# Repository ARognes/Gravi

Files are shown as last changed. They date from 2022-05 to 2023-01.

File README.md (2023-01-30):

# Gravi

This is a 42 or 36 key, bluetooth keyboard with at least 100mAh battery life per side

Idk exactly what to call this keyboard. The main focus of it is to eliminate the extra area where the system on a chip (SoC) is commonly located. However I've gotten carried away and removed much more. 

A minimal amount of tenting will be required to hold the battery underneath.

## Names:
- Estoc
- Crawlerboard
- Gravby
- Gravbi
- Gravi
- Gravi
- Mash
- Contour Split
- Ergo Berry
- Skeleberry
- DexBerry

## Features:
- Split in 2 halves
- Bluetooth low energy
- nRF52 family
- On-board SMD components
- No center microcontroller area
- Minimal visible space without keys
- Battery underneath tenting towards usb-c edge
- Milmax sockets

There may be 2 sizes for standard and low profile switch types
- Cherry MX / Kailh
- Kailh choc

The main focus is the Kailh choc board (low profile).

Rohs and FCC compliance will be a hurdle.
A case will need to be built, by this time aesthetics will be more of a concern.

# Schematic
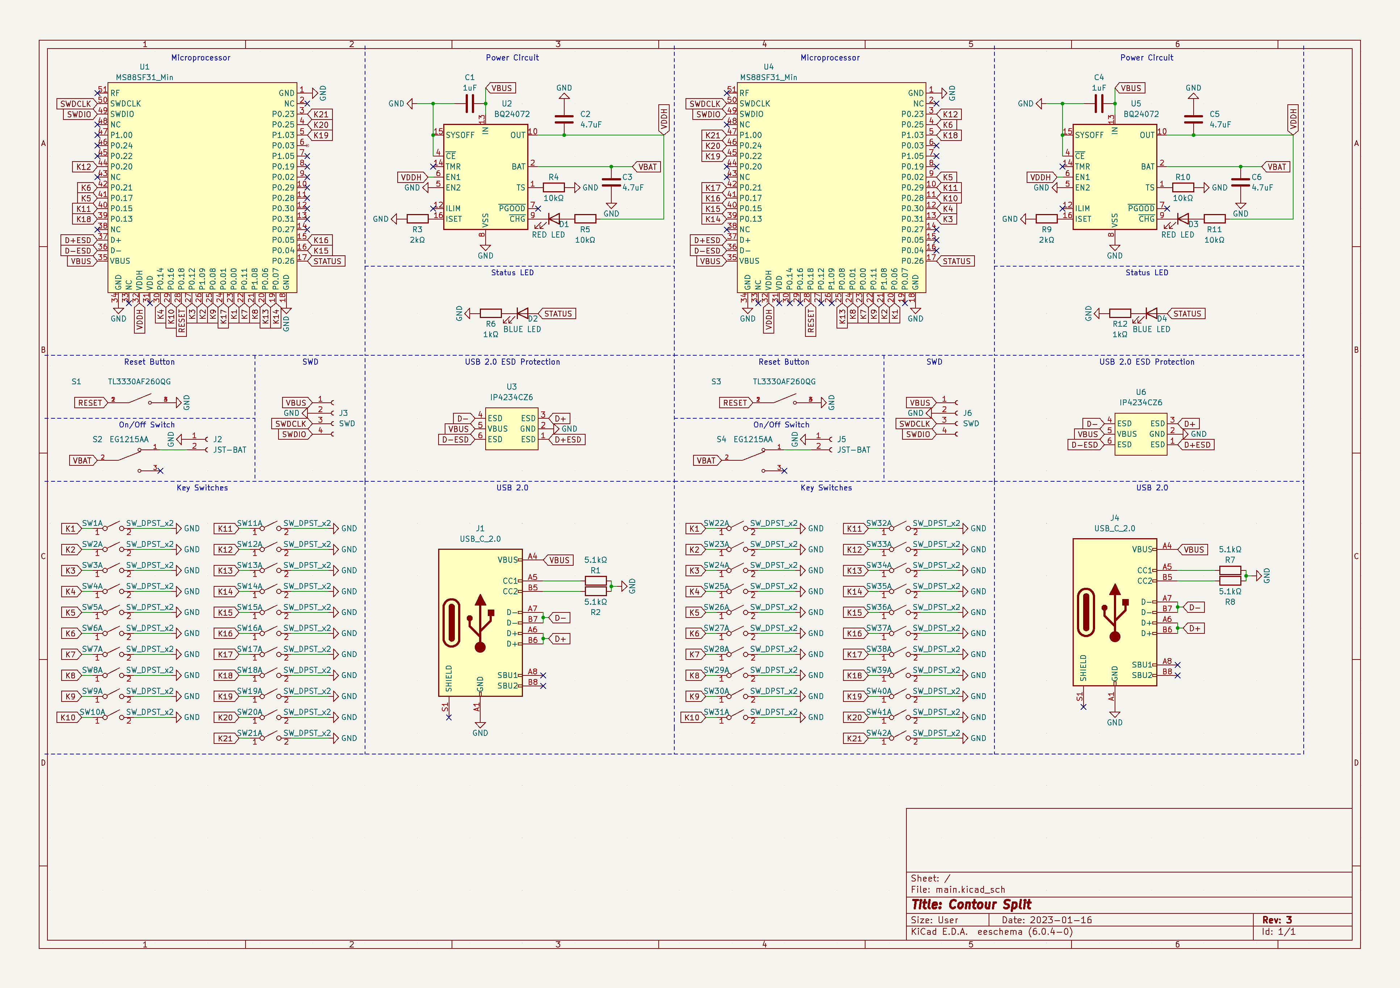
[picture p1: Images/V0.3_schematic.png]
Schematic

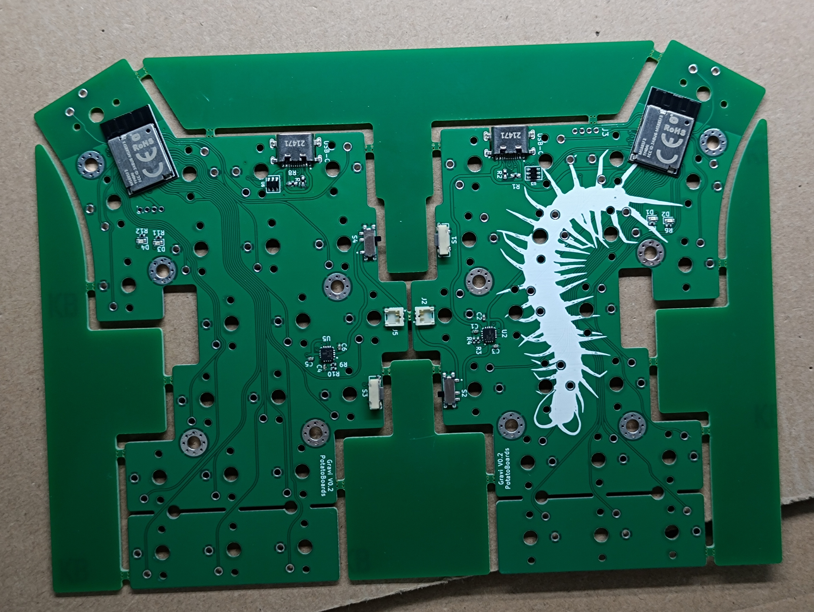
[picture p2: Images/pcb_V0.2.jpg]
Render


# Prototypes
Prototype

# Revision 4
(Looks the same as rev 3)

# Revision 3
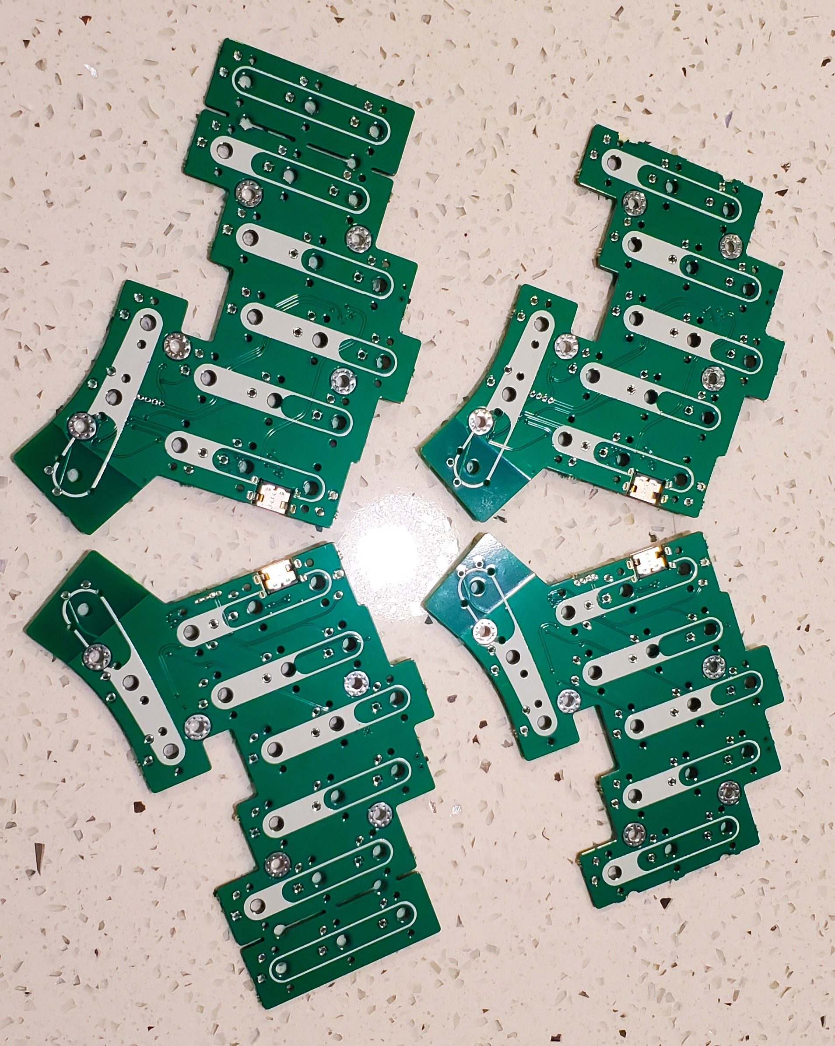
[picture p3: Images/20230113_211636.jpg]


# Revision 2
(Looks the same as rev 3)

# Revision 1
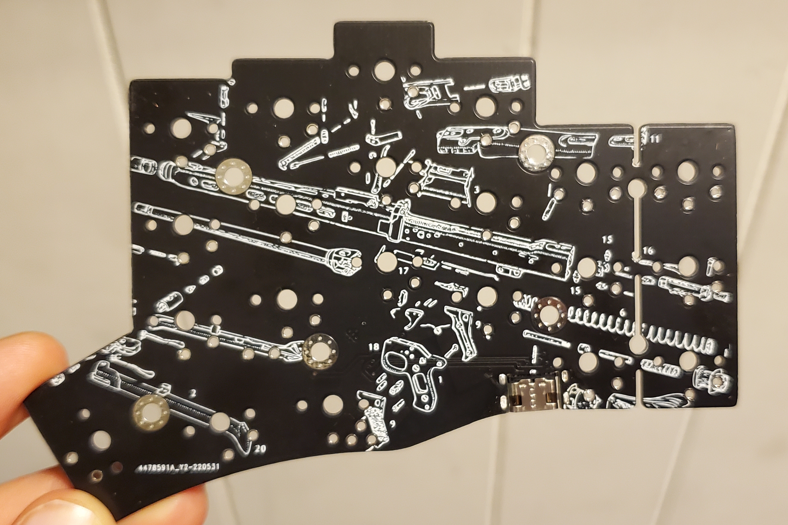
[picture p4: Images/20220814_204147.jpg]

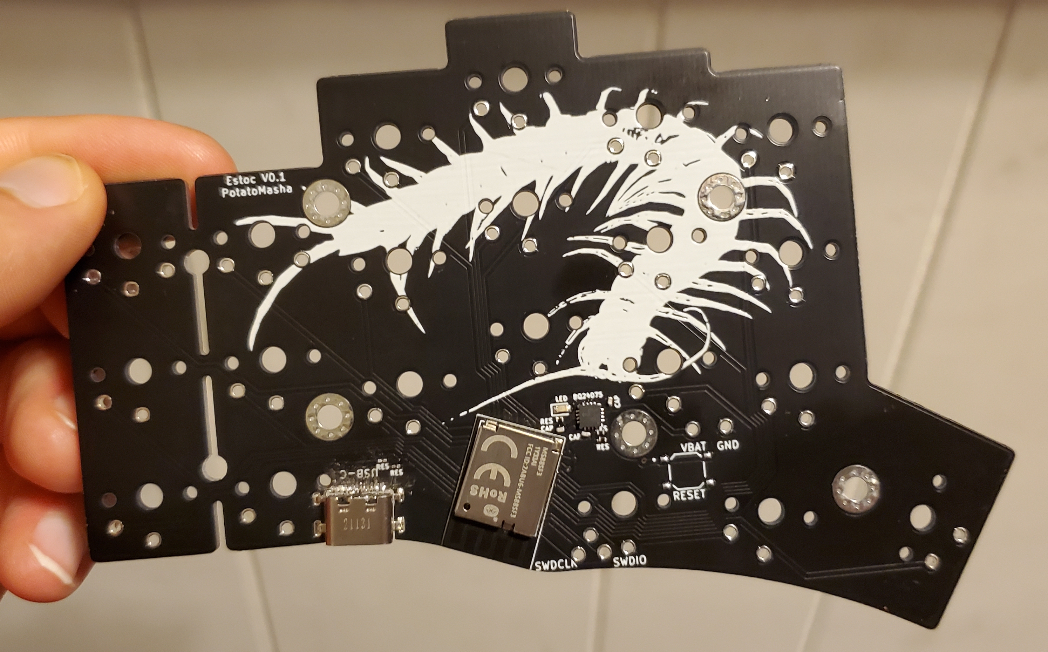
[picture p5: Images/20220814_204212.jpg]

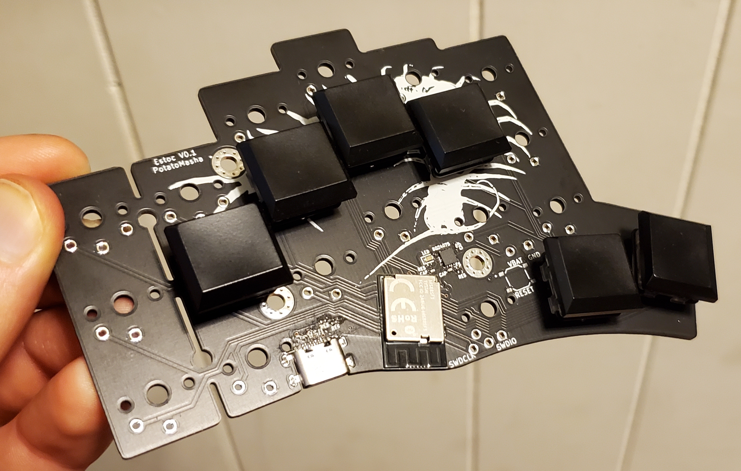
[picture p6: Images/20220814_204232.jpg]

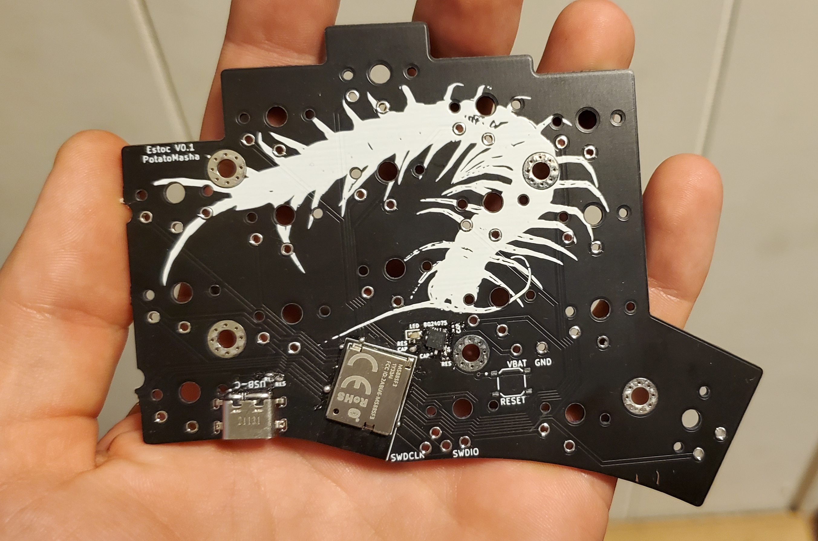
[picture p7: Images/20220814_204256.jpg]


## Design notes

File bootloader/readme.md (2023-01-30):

# About
Load the .hex bootloader onto any Gravi board over SWD. Use a Segger JLink, Black Magic Probe, Development Kit, or any other SWD programmer.

# How do I make modifications?
The [Adafruit_nRF52_Bootloader](https://github.com/adafruit/Adafruit_nRF52_Bootloader) repo has instructions on building the code for this hex file. Many hex files will be generated, use the nosd version.

`gravi/` is the board .h files used to decide pin placements and documentation.

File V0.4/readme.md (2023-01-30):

# V0.4 - Ordered Jan 30, 2023
After much testing and debugging of the previous two versions, it was decided that working with an nrf52840 would be easier. This is because the .hex bootloader could be pre-programmed by Minew. The bootloader has UF2 capabilities so the keyboard could simply be programmed over USB and no SWD would be required.

# Changes
- nrf52840 instead of nrf52833
- corrected resistor pad sizes from 0603 to 0402
- pre-install bootloader before soldering
- specify soldering max temp during assembly

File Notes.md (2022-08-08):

# Estoc

[Attribution-NonCommercial-ShareAlike 4.0 International (CC BY-NC-SA 4.0)](https://creativecommons.org/licenses/by-nc-sa/4.0/)

## Battery
1000mAh is a good cuttoff point before diminishing returns
20% main will be wasted
70% peripheral will be wasted

If main alternation is available, this may be better aleviated

Anything >= 600mAh works really

(mm)
YOK Energy: 
  YE602663C  6.2  26.3  63.5 

[LiPol Battery](https://www.lipo-battery.com/r)
LP602760: 60	27	6 
LP602660: 60	26	6 
LP602560: 60	25	6 
LP603443: 43  34  6

Ask for JST connectors attached!

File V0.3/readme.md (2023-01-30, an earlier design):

# V0.3 Ordered - 
Uses normal-voltage mode, 3.3V over VDD + VDDH.

# Issues
When plugged in to usb-c, the MS88SF31 module on board gets very hot very quickly, > 85 Celcius don't touch the board hot.

The J-Link SWD interface does not work and I am not able to program the nrf52833.

I think the issue is with the battery and that the MS88SF31 is either getting too much or too little voltage. The Texas Instruments BQ24072 may be at fault here.

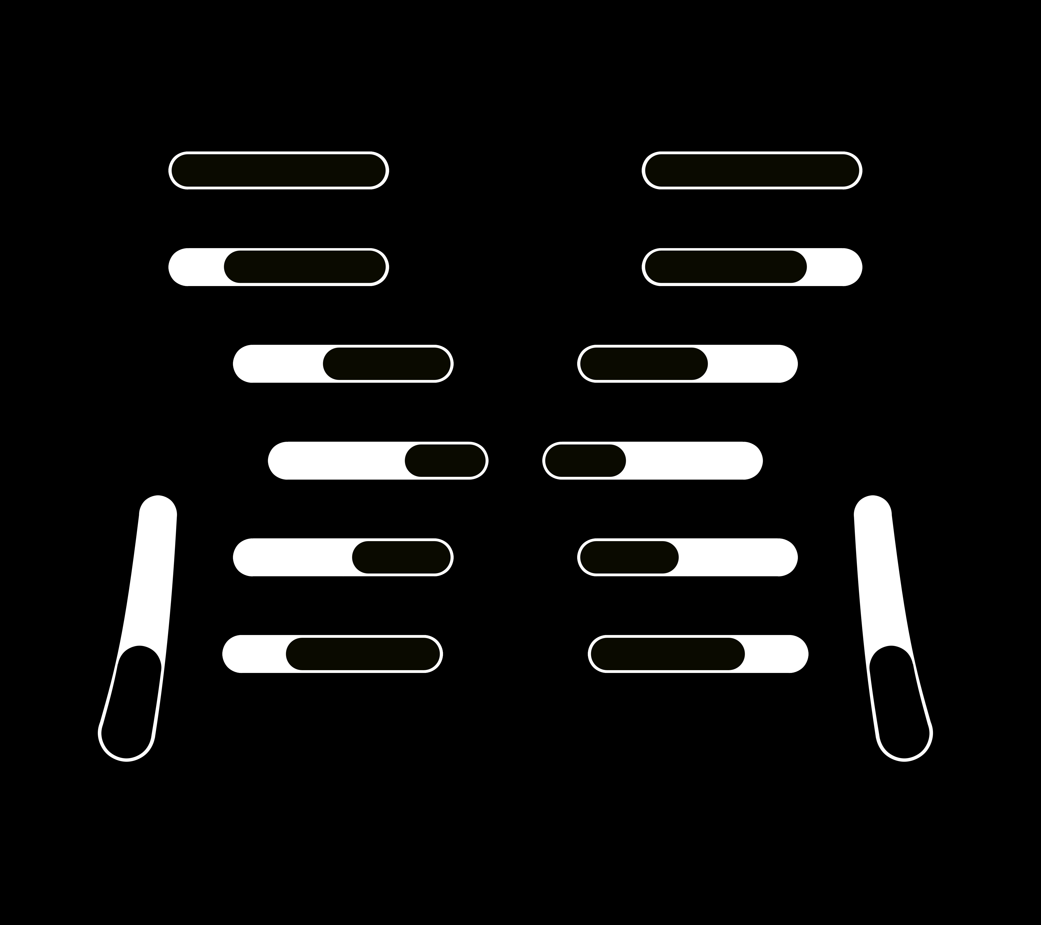
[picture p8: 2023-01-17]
V0.4/Choc/overlay.png

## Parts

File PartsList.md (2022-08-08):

# Parts List

All possible parts to select for the BOM

---

## Capacitors: Digikey, YAGEO
|  QTY | Price  | Capacitance | Need  | Company |
| :----: | :----: | :---: | :---: | :---: |
| 5,000  | $76.15 | 12 pF | 2 | [YAGEO](https://www.digikey.com/en/products/detail/yageo/CC0402FRNPO9BN120/5195050) |
| 5,000  | $38.20 | 4.7 pF | 2 | [YAGEO](https://www.digikey.com/en/products/detail/yageo/CC0402BRNPO9BN4R7/5195033) |
| 5,000  | $32.25 | 1 pF | 1 | [YAGEO](https://www.digikey.com/en/products/detail/yageo/CC0402BRNPO9BN1R0/5883183) |
| 10,000 | $62.60 | 12pF | 2 | [Venkel](https://www.digikey.com/en/products/detail/venkel/C0402C0G500-120FNP/12332097) |

1005 Metric

Venkel has free shipping

---

## Resistors
| Name | In Stock |  QTY | Price  | Resistance | Datasheet | Company |
| :---: | :---: | :----: | :----: | :---: | :---: | ---: |
|  RC0402FR-0710KP  | 174,000  | 1,000  | $6.52  | 10 kΩ | [DS](https://www.yageo.com/upload/media/product/productsearch/datasheet/rchip/PYu-RC_51_RoHS_P_2.pdf) | [YAGEO](https://www.digikey.com/en/products/detail/yageo/RC0402FR-0710KP/4935264) |
|  RC0402FR-072KP | 110,000  | 1,000  | $6.52  | 2 kΩ | [DS](https://www.yageo.com/upload/media/product/productsearch/datasheet/rchip/PYu-RC_51_RoHS_P_2.pdf) | [YAGEO](https://www.digikey.com/en/products/detail/yageo/RC0402FR-072KP/4935276) |
| CR0402-16W-5101FT | Many | 10,000 | $15.40 | 5.1 kΩ | [DS](https://page.venkel.com/hubfs/Resources/Datasheets/CR-Series.pdf) | [Venkel](https://www.digikey.com/en/products/detail/venkel/CR0402-16W-5101FT/12327266) |
|  RC0402FR-7W1KL |  6,000 | 1,000  | $4.51  | 1 kΩ | [DS](https://www.yageo.com/upload/media/product/productsearch/datasheet/rchip/PYu-RC_Group_51_RoHS_L_11.pdf) | [YAGEO](https://www.digikey.com/en/products/detail/yageo/RC0402FR-7W1KL/12698822) |

1005 Metric

Possibly need 1k resistor

Venkel has free shipping

---

## Crystals

| Name |  Size mm  |  QTY  | In Stock |  Price  | Datasheet | Distributor |
| :---: | :---: | :---: | :---: | :-----: | :---: | :---: |
| FC-12M 32.7680KA-AC3 | 2.05x1.25 |  250  |  51,000  | $277.20 | [DS](https://support.epson.biz/td/api/doc_check.php?dl=brief_FC-12D&lang=en) | [Digikey](https://www.digikey.com/en/products/detail/epson/FC-12M-32.7680KA-AC3/5259892) |
| CM8V-T1A.. |  2.0x1.2  | 1,000 |  83,000  | $350.24 | [DS](https://www.microcrystal.com/fileadmin/Media/Products/32kHz/Datasheet/CM8V-T1A.pdf) | [Digikey](https://www.digikey.com/en/products/detail/micro-crystal-ag/CM8V-T1A-32.768KHZ-9PF-20PPM-TA-QC/10500166) |

---

## Power / Charging Chip

| Name |  QTY  | In Stock | Price | Datasheet | Distributor |
| :---: | :---: | :---: | :---: | :---: | :---: |
| BQ24075RGTR | 1,000 |  12,000  | $2,876.69 | [DS](https://pdf.utmel.com/r/datasheets/texasinstruments-bq24075rgtr-datasheets-3513.pdf) | [Utmel](https://www.utmel.com/productdetail/texasinstruments-bq24075rgtr-9878457) |
| BQ24076RGTT | 1,000 | 736 | $1,697.50 | [DS](https://www.ti.com/general/docs/suppproductinfo.tsp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) | [Digikey](https://www.digikey.com/en/products/detail/texas-instruments/BQ24076RGTT/7915907) |
| BQ24076GTR  | 1,000 |  3,623 | $1,414.00 | [DS](https://www.ti.com/general/docs/suppproductinfo.tsp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) | [Digikey](https://www.digikey.com/en/products/detail/texas-instruments/BQ24076RGTR/8105808) |
| BQ24076RGTR | 1,000 | 235,397  | $808 | [DS](https://www.ti.com/document-viewer/BQ24076/datasheet) | [Texas Instruments](https://www.ti.com/product/BQ24076?login-check=true) |
| BQ24072RGTR | 1,000 | 136,747  | $808 | [DS](https://www.ti.com/lit/gpn/BQ24072) | [Texas Instruments](https://www.ti.com/product/BQ24072/part-details/BQ24072RGTR) |

BQ24072 should be used as it has battery charge voltage min & max of 4.2 V,
exactly what a 3.7 V battery needs.

Switch and Pulse chargers also exist but 

XC6220B331MR-G is a voltage regulator.
It outputs 3.3 V minimum, 1 A current
Input max 6 V

---

## JST Battery Connector

|  End | Name | In Stock |  QTY  |  Price  | Datasheet | Distributor |
| :----: | :---: | :---: | :---: | :-----: | :---: | :---: |
| Female | BM02B-ACHSS-GAN-TF(LF)(SN) | 422,000  | 1,000 | $287.44 | [DS](https://media.digikey.com/pdf/Data%20Sheets/JST%20PDFs/ACH_1.2Pitch_DisconnectableCrimp.pdf) | [Digikey](https://www.digikey.com/en/products/detail/jst-sales-america-inc/BM02B-ACHSS-GAN-TF-LF-SN/1647788) |
|  Male  | ACHR-02V-S |  43,550  | 1,000 | $73.43  | [DS](https://www.jst-mfg.com/product/pdf/eng/eACH.pdf) | [Digikey](https://www.digikey.com/en/products/detail/jst-sales-america-inc/ACHR-02V-S/1647783) |

---

## USB-C

| Name | In Stock |  QTY  |  Price  | Datasheet | Distributor |
| :---: | :---: | :---: | :-----: | :---: | :---: |
| 2169900003 |  5,110 | 1,000 | $723.24 | | |
| 2169900001 |  5,110 | 1,000 | $723.24 | [DS](https://www.molex.com/webdocs/datasheets/pdf/en-us/2169900001_IO_CONNECTORS.pdf) | [Digikey](https://www.digikey.com/en/products/detail/molex/2169900001/13913743?s=N4IgTCBcDa4IwDYCcSAM7VxAXQL5A) |

---

## USB-C ESD Protection
| Name | In Stock |  QTY  |  Price  | Datasheet | Distributor |
| :---: | :---: | :---: | :-----: | :---: | :---: |
| RCLAMP7522T.TNT | 8,821 | 1,000 | $495 | [DS](https://semtech.my.salesforce.com/sfc/p/E0000000JelG/a/2R000000HTqQ/iEJdTMWfTgfi7KiSi1OQ6ZvqU_A4rcQHQVQUbS4fs.w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) | [Mouser](https://www.mouser.com/ProductDetail/Semtech/RCLAMP7522TTNT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) |
| IP4234CZ6,125 | 21,000 | 1,000 | $158.20 | [DS](https://assets.nexperia.com/documents/data-sheet/IP4234CZ6.pdf) | [Digikey](https://www.digikey.com/en/products/detail/IP4234CZ6,125/1727-4717-2-ND/2296236?utm_campaign=buynow&utm_medium=aggregator&curr=usd&utm_source=octopart) |

---

## LED

| Name | Color | In Stock |  QTY  | Price  | Datasheet | Distributor |
| :---: | :---: | :---: | :---: | :----: | :---: | :---: |
| SML-D12U1WT86 |  Red  |  6,000 | 1,000 | $39.86 | [DS](https://fscdn.rohm.com/en/products/databook/datasheet/opto/led/chip_mono/sml-d12x1-e.pdf) | [Digikey](https://www.digikey.com/en/products/detail/rohm-semiconductor/SML-D12U1WT86/5843853) |
| SML-D12U1WT86 | Green |  6,000 | 1,000 | $39.86 | [DS](https://fscdn.rohm.com/en/products/databook/datasheet/opto/led/chip_mono/sml-d12x1-e.pdf) | [Digikey](https://www.digikey.com/en/products/detail/rohm-semiconductor/SML-D12M1WT86/5843856) |

---

## Mill Max Socket

| 7305-0-15-15-47-27-10-0 | 230,813 | 50,000 | $7,250 | (DS)[https://www.mouser.com/datasheet/2/273/MMMC_S_A0005142907_1-2558040.pdf] | (Mouser)[https://www.mouser.com/ProductDetail/Mill-Max/7305-0-15-15-47-27-10-0?qs=QVz7UnnaAAGZJgZDI7Hd%2FA%3D%3D]
| 3305-0-15-80-47-27-10-0 | 60,000  | 50,000 | $8,200 | (DS)[https://www.mouser.com/datasheet/2/273/mill_max_02192021_3305_0_15_80_47_27_10_0-2036622.pdf] | (Mouser)[https://www.mouser.com/ProductDetail/Mill-Max/3305-0-15-80-47-27-10-0?qs=CiayqK2gdcJ0UcFbwoRx4A%3D%3D]

---
## Switch

## Reset Button

# Alternate Power / Charging Circuit DON't DO THIS

Gotta beat $808 / 1,000

TP4054ST25K | 2,500 | $125 | [LCSC](https://www.lcsc.com/product-detail/PMIC-Battery-Management_TPOWER-TP4054ST25P_C382138.html)
Mosfet
Schottky Diode

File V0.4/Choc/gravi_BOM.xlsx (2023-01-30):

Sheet: Revison 2
PCBWay Bom Quotation, Product No.:T-Y6W429874A
Item # | *Designator | *Qty | Manufacturer | *Mfg Part # | Description / Value | Your Instructions / Notes | *Unit Price (5 sets) | *Total | *Delivery Time | *PCBWay Note | Customer Reply | PCBWay Update
1 | C1,C4 | 2 | KYOCERA AVX | 04023D105KAT2A | 1 µF ±10% 25V Ceramic Capacitor X5R 0402 (1005 Metric) | Yes『 』https://datasheets.kyocera-avx.com/C0GNP0-Dielectric.pdf | $0.092 | $0.920
2 | C2,C3,C5,C6 | 4 | KYOCERA AVX | 0402YD475MAT2A | 4.7 µF ±20% 16V Ceramic Capacitor X5R 0402 (1005 Metric) | Yes『 』https://datasheets.kyocera-avx.com/cx5r.pdf | $0.139 | $2.780
3 | D1,D3 | 2 | Lite-On Inc. | LTST-C193KRKT-5A | LED Red 0603 (1608 Metric) 2VF 5mA IF | Yes『 』https://optoelectronics.liteon.com/upload/download/DS22-2005-077/LTST-C193KRKT-5A.PDF | $0.139 | $1.390
4 | D2,D4 | 2 | Lite-On Inc. | LTST-C194TBKT | LED Blue 0603 (1608 Metric) 3.3VF 20mA IF | Yes『 』https://optoelectronics.liteon.com/upload/download/DS22-2010-0025/LTST-C194TBKT.PDF | $0.117 | $1.170
5 | J1,J4 | 2 | Molex | 2169900003 | Connector:USB_C_Receptacle_USB2.0 | No『 』https://www.molex.com/webdocs/datasheets/pdf/en-us/2169900003_IO_CONNECTORS.pdf | $1.012 | $10.120 | 7-10 Workdays
6 | J2,J5 | 2 | ACH Connector | BM02B-ACHSS-GAN-TF(LF)(SN) | Connector:Conn_01x02_Female | No『 』https://media.digikey.com/pdf/Data%20Sheets/JST%20PDFs/ACH_1.2Pitch_DisconnectableCrimp.pdf | $0.357 | $3.570
7 | R1,R2,R7,R8 | 4 | Panasonic Electronic Components | ERJ-U02F5101X | 5.1 kOhms ±1% 0.1W, 1/10W Chip Resistor 0402 (1005 Metric) Anti-Sulfur, Automotive AEC-Q200 Thick Film | Yes『 』https://industrial.panasonic.com/cdbs/www-data/pdf/RDP0000/AOA0000C334.pdf | $0.139 | $2.780
8 | R3,R4,R9,R10 | 4 | Yageo | RC0402FR-7W10KL | 10 kOhms ±1% 0.125W, 1/8W Chip Resistor 0402 (1005 Metric) Moisture Resistant Thick Film | Yes『 』https://www.yageo.com/upload/media/product/productsearch/datasheet/rchip/PYu-RC_Group_51_RoHS_L_11.pdf | $0.017 | $0.340
9 | R5,R11 | 2 | Panasonic Electronic Components | ERJ-2RKF4700X | 470 Ohms ±1% 0.1W, 1/10W Chip Resistor 0402 (1005 Metric) Automotive AEC-Q200 Thick Film | Yes『 』https://industrial.panasonic.com/cdbs/www-data/pdf/RDA0000/AOA0000C304.pdf | $0.046 | $0.460
10 | R6,R12 | 2 | Panasonic Electronic Components | ERJ-2RKF62R0X | 62 Ohms ±1% 0.1W, 1/10W Chip Resistor 0402 (1005 Metric) Automotive AEC-Q200 Thick Film | Yes『 』https://industrial.panasonic.com/cdbs/www-data/pdf/RDA0000/AOA0000C304.pdf | $0.050 | $0.500
11 | S1,S3 | 2 | E Switch | TL3330AF260QG | Push button | No『 』https://sten-eswitch-13110800-production.s3.amazonaws.com/system/asset/product_line/data_sheet/163/TL3330.pdf | $0.423 | $4.230
12 | S2,S4 | 2 | E Switch | EG1215AA | On/off switch | No『 』https://media.digikey.com/pdf/Data%20Sheets/E-Switch%20PDFs/EG1215_Series_Ds.pdf | $1.292 | $12.920 | 7-10 Workdays
13 | U1,U4 | 2 | Minew | MS88SF3 (nrf52840) | BLE module | No『 』https://www.minew.com/uploads/MS88SF3_V1.1-nRF52840-Datasheet.pdf
14 | U2,U5 | 2 | Texas Instruments | BQ24072RGTR | Battery management | No『 』https://www.ti.com/lit/gpn/BQ24072 | $1.374 | $13.740
15 | U3,U6 | 2 | Nexperia | IP4234CZ6 | ESD protection for USB 2.0 | No『 』https://assets.nexperia.com/documents/data-sheet/IP4234CZ6.pdf | $0.603 | $6.030
 |  |  |  |  |  |  | All Total | $60.950

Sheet: Revision 1
PCBWay Bom Quotation, Product No.:T-Y6W429874A
Item # | *Designator | *Qty | Manufacturer | *Mfg Part # | Description / Value | Your Instructions / Notes | *Unit Price (5 sets) | *Total | *Delivery Time | *PCBWay Note | Customer Reply | PCBWay Update
1 | C1,C4 | 2 | KYOCERA AVX | 04023D105KAT2A | 1 碌F 卤10% 25V Ceramic Capacitor X5R 0402 (1005 Metric) | Yes『 』https://datasheets.kyocera-avx.com/C0GNP0-Dielectric.pdf | $0.092 | $0.920
2 | C2,C3,C5,C6 | 4 | KYOCERA AVX | 0402YD475MAT2A | 4.7 碌F 卤20% 16V Ceramic Capacitor X5R 0402 (1005 Metric) | Yes『 』https://datasheets.kyocera-avx.com/cx5r.pdf | $0.139 | $2.780
3 | D1,D3 | 2 | Lite-On Inc. | LTST-C193KRKT-5A | LED Red 0603 (1608 Metric) 2VF 5mA IF | Yes『 』https://optoelectronics.liteon.com/upload/download/DS22-2005-077/LTST-C193KRKT-5A.PDF | $0.139 | $1.390
4 | D2,D4 | 2 | Lite-On Inc. | LTST-C194TBKT | LED Blue 0603 (1608 Metric) 3.3VF 20mA IF | Yes『 』https://optoelectronics.liteon.com/upload/download/DS22-2010-0025/LTST-C194TBKT.PDF | $0.117 | $1.170
5 | J1,J4 | 2 | Molex | 2169900003 | Connector:USB_C_Receptacle_USB2.0 | No『 』https://www.molex.com/webdocs/datasheets/pdf/en-us/2169900003_IO_CONNECTORS.pdf | $0.984 | $9.840 | 7-10 Workdays
6 | J2,J5 | 2 | ACH Connector | BM02B-ACHSS-GAN-TF(LF)(SN) | Connector:Conn_01x02_Female | No『 』https://media.digikey.com/pdf/Data%20Sheets/JST%20PDFs/ACH_1.2Pitch_DisconnectableCrimp.pdf | $0.357 | $3.570
7 | R1,R2,R7,R8 | 4 | Panasonic Electronic Components | ERJ-U02F5101X | 5.1 kOhms 卤1% 0.1W, 1/10W Chip Resistor 0402 (1005 Metric) Anti-Sulfur, Automotive AEC-Q200 Thick Film | Yes『 』https://industrial.panasonic.com/cdbs/www-data/pdf/RDP0000/AOA0000C334.pdf | $0.139 | $2.780
8 | R3,R4,R9,R10 | 4 | Yageo | RC0402FR-7W10KL | 10 kOhms 卤1% 0.125W, 1/8W Chip Resistor 0402 (1005 Metric) Moisture Resistant Thick Film | Yes『 』https://www.yageo.com/upload/media/product/productsearch/datasheet/rchip/PYu-RC_Group_51_RoHS_L_11.pdf | $0.210 | $4.200 |  | Plz confirm if qty here should be 4 instead of 2? Should be 4
9 | R5,R11 | 2 | Panasonic Electronic Components | ERJ-2RKF4700X | 470 Ohms 卤1% 0.1W, 1/10W Chip Resistor 0402 (1005 Metric) Automotive AEC-Q200 Thick Film | Yes『 』https://industrial.panasonic.com/cdbs/www-data/pdf/RDA0000/AOA0000C304.pdf | $0.046 | $0.460 |  | Plz confirm if qty here should be 2 instead of 4? Should be 2
10 | R6,R12 | 2 | Panasonic Electronic Components | ERJ-2RKF62R0X | 62 Ohms 卤1% 0.1W, 1/10W Chip Resistor 0402 (1005 Metric) Automotive AEC-Q200 Thick Film | Yes『 』https://industrial.panasonic.com/cdbs/www-data/pdf/RDA0000/AOA0000C304.pdf | $0.050 | $0.500
11 | S1,S3 | 2 | E Switch | TL3330AF260QG | Push button | No『 』https://sten-eswitch-13110800-production.s3.amazonaws.com/system/asset/product_line/data_sheet/163/TL3330.pdf | $0.423 | $4.230
12 | S2,S4 | 2 | E Switch | EG1215AA | On/off switch | No『 』https://media.digikey.com/pdf/Data%20Sheets/E-Switch%20PDFs/EG1215_Series_Ds.pdf | $1.256 | $12.560 | 7-10 Workdays
13 | U1,U4 | 2 | Minew | MS88SF31 | BLE module | No『 』https://www.minew.com/wp-content/uploads/2021/05/MS88SF3_V1.1-nRF52840-Datasheet.pdf |  |  |  | [It's out of stock. Please recommend substitutes or you can supply this part to us.]
14 | U2,U5 | 2 | Texas Instruments | BQ24072RGTR | Battery management | No『 』https://www.ti.com/lit/gpn/BQ24072 |  |  |  | Pls provide the complete part number.According to your link, we can't know which part you want. I can supply this if needed
15 | U3,U6 | 2 | Nexperia | IP4234CZ6 | ESD protection for USB 2.0 | No『 』https://assets.nexperia.com/documents/data-sheet/IP4234CZ6.pdf | $0.603 | $6.030
 |  |  |  |  |  |  | All Total | $50.430

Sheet: BOM
Source: | /Users/austinrognes/Desktop/Estoc/V0.2/Choc/main.kicad_sch
Date: | Sunday, August 14, 2022 at 06:41:24 PM
Tool: | Eeschema (6.0.4-0)
Generator: | /Applications/KiCad/KiCad.app/Contents/SharedSupport/plugins/bom_csv_grouped_by_value.py
Component Count: | 36
Individual Components:
Item | Qty | Reference(s) | MFG | Description/Value | Manufacturer | Replaceable | Datasheet
 | 1 | C1 | 04023D105KAT2A | 1 µF ±10% 25V Ceramic Capacitor X5R 0402 (1005 Metric) | KYOCERA AVX | Yes | https://datasheets.kyocera-avx.com/C0GNP0-Dielectric.pdf
 | 1 | C2 | 0402YD475MAT2A | 4.7 µF ±20% 16V Ceramic Capacitor X5R 0402 (1005 Metric) | KYOCERA AVX | Yes | https://datasheets.kyocera-avx.com/cx5r.pdf
 | 1 | C3 | 0402YD475MAT2A | 4.7 µF ±20% 16V Ceramic Capacitor X5R 0402 (1005 Metric) | KYOCERA AVX | Yes | https://datasheets.kyocera-avx.com/cx5r.pdf
 | 1 | C4 | 04023D105KAT2A | 1 µF ±10% 25V Ceramic Capacitor X5R 0402 (1005 Metric) | KYOCERA AVX | Yes | https://datasheets.kyocera-avx.com/C0GNP0-Dielectric.pdf
 | 1 | C5 | 0402YD475MAT2A | 4.7 µF ±20% 16V Ceramic Capacitor X5R 0402 (1005 Metric) | KYOCERA AVX | Yes | https://datasheets.kyocera-avx.com/cx5r.pdf
 | 1 | C6 | 0402YD475MAT2A | 4.7 µF ±20% 16V Ceramic Capacitor X5R 0402 (1005 Metric) | KYOCERA AVX | Yes | https://datasheets.kyocera-avx.com/cx5r.pdf
 | 1 | D1 | LTST-C193KRKT-5A | LED Red 0603 (1608 Metric) 2VF 5mA IF | Lite-On Inc. | Yes | https://optoelectronics.liteon.com/upload/download/DS22-2005-077/LTST-C193KRKT-5A.PDF
 | 1 | D2 | LTST-C194TBKT | LED Blue 0603 (1608 Metric) 3.3VF 20mA IF | Lite-On Inc. | Yes | https://optoelectronics.liteon.com/upload/download/DS22-2010-0025/LTST-C194TBKT.PDF
 | 1 | D3 | LTST-C193KRKT-5A | LED Red 0603 (1608 Metric) 2VF 5mA IF | Lite-On Inc. | Yes | https://optoelectronics.liteon.com/upload/download/DS22-2005-077/LTST-C193KRKT-5A.PDF
 | 1 | D4 | LTST-C194TBKT | LED Blue 0603 (1608 Metric) 3.3VF 20mA IF | Lite-On Inc. | Yes | https://optoelectronics.liteon.com/upload/download/DS22-2010-0025/LTST-C194TBKT.PDF
 | 1 | J1 | 2169900003 | Connector:USB_C_Receptacle_USB2.0 | Molex | No | https://www.molex.com/webdocs/datasheets/pdf/en-us/2169900003_IO_CONNECTORS.pdf (https://www.usb.org/sites/default/files/documents/usb_type-c.zip)
 | 1 | J2 | BM02B-ACHSS-GAN-TF(LF)(SN) | Connector:Conn_01x02_Female | ACH Connector | No | https://media.digikey.com/pdf/Data%20Sheets/JST%20PDFs/ACH_1.2Pitch_DisconnectableCrimp.pdf
 | 1 | J4 | 2169900003 | Connector:USB_C_Receptacle_USB2.0 | Molex | No | https://www.molex.com/webdocs/datasheets/pdf/en-us/2169900003_IO_CONNECTORS.pdf (https://www.usb.org/sites/default/files/documents/usb_type-c.zip)
 | 1 | J5 | BM02B-ACHSS-GAN-TF(LF)(SN) | Connector:Conn_01x02_Female | ACH Connector | No | https://media.digikey.com/pdf/Data%20Sheets/JST%20PDFs/ACH_1.2Pitch_DisconnectableCrimp.pdf
 | 1 | R1 | ERJ-U02F5101X | 5.1 kOhms ±1% 0.1W, 1/10W Chip Resistor 0402 (1005 Metric) Anti-Sulfur, Automotive AEC-Q200 Thick Film | Panasonic Electronic Components | Yes | https://industrial.panasonic.com/cdbs/www-data/pdf/RDP0000/AOA0000C334.pdf
 | 1 | R2 | ERJ-U02F5101X | 5.1 kOhms ±1% 0.1W, 1/10W Chip Resistor 0402 (1005 Metric) Anti-Sulfur, Automotive AEC-Q200 Thick Film | Panasonic Electronic Components | Yes | https://industrial.panasonic.com/cdbs/www-data/pdf/RDP0000/AOA0000C334.pdf
 | 1 | R3 | RC0402FR-7W10KL | 10 kOhms ±1% 0.125W, 1/8W Chip Resistor 0402 (1005 Metric) Moisture Resistant Thick Film | Yageo | Yes | https://www.yageo.com/upload/media/product/productsearch/datasheet/rchip/PYu-RC_Group_51_RoHS_L_11.pdf
 | 1 | R4 | RC0402FR-7W10KL | 10 kOhms ±1% 0.125W, 1/8W Chip Resistor 0402 (1005 Metric) Moisture Resistant Thick Film | Yageo | Yes | https://www.yageo.com/upload/media/product/productsearch/datasheet/rchip/PYu-RC_Group_51_RoHS_L_11.pdf
 | 1 | R5 | ERJ-2RKF4700X | 470 Ohms ±1% 0.1W, 1/10W Chip Resistor 0402 (1005 Metric) Automotive AEC-Q200 Thick Film | Panasonic Electronic Components | Yes | https://industrial.panasonic.com/cdbs/www-data/pdf/RDA0000/AOA0000C304.pdf
 | 1 | R6 | ERJ-2RKF62R0X | 62 Ohms ±1% 0.1W, 1/10W Chip Resistor 0402 (1005 Metric) Automotive AEC-Q200 Thick Film | Panasonic Electronic Components | Yes | https://industrial.panasonic.com/cdbs/www-data/pdf/RDA0000/AOA0000C304.pdf
 | 1 | R7 | ERJ-U02F5101X | 5.1 kOhms ±1% 0.1W, 1/10W Chip Resistor 0402 (1005 Metric) Anti-Sulfur, Automotive AEC-Q200 Thick Film | Panasonic Electronic Components | Yes | https://industrial.panasonic.com/cdbs/www-data/pdf/RDP0000/AOA0000C334.pdf
 | 1 | R8 | ERJ-U02F5101X | 5.1 kOhms ±1% 0.1W, 1/10W Chip Resistor 0402 (1005 Metric) Anti-Sulfur, Automotive AEC-Q200 Thick Film | Panasonic Electronic Components | Yes | https://industrial.panasonic.com/cdbs/www-data/pdf/RDP0000/AOA0000C334.pdf
 | 1 | R9 | RC0402FR-7W10KL | 10 kOhms ±1% 0.125W, 1/8W Chip Resistor 0402 (1005 Metric) Moisture Resistant Thick Film | Yageo | Yes | https://www.yageo.com/upload/media/product/productsearch/datasheet/rchip/PYu-RC_Group_51_RoHS_L_11.pdf
 | 1 | R10 | RC0402FR-7W10KL | 10 kOhms ±1% 0.125W, 1/8W Chip Resistor 0402 (1005 Metric) Moisture Resistant Thick Film | Yageo | Yes | https://www.yageo.com/upload/media/product/productsearch/datasheet/rchip/PYu-RC_Group_51_RoHS_L_11.pdf
 | 1 | R11 | ERJ-2RKF4700X | 470 Ohms ±1% 0.1W, 1/10W Chip Resistor 0402 (1005 Metric) Automotive AEC-Q200 Thick Film | Panasonic Electronic Components | Yes | https://industrial.panasonic.com/cdbs/www-data/pdf/RDA0000/AOA0000C304.pdf
 | 1 | R12 | ERJ-2RKF62R0X | 62 Ohms ±1% 0.1W, 1/10W Chip Resistor 0402 (1005 Metric) Automotive AEC-Q200 Thick Film | Panasonic Electronic Components | Yes | https://industrial.panasonic.com/cdbs/www-data/pdf/RDA0000/AOA0000C304.pdf
 | 1 | S1 | TL3330AF260QG | Push button | E Switch | No | https://sten-eswitch-13110800-production.s3.amazonaws.com/system/asset/product_line/data_sheet/163/TL3330.pdf
 | 1 | S2 | EG1215AA | On/off switch | E Switch | No | https://media.digikey.com/pdf/Data%20Sheets/E-Switch%20PDFs/EG1215_Series_Ds.pdf
 | 1 | S3 | TL3330AF260QG | Push button | E Switch | No | https://sten-eswitch-13110800-production.s3.amazonaws.com/system/asset/product_line/data_sheet/163/TL3330.pdf
 | 1 | S4 | EG1215AA | On/off switch | E Switch | No | https://media.digikey.com/pdf/Data%20Sheets/E-Switch%20PDFs/EG1215_Series_Ds.pdf
 | 1 | U1 | MS88SF31 | BLE module | Minew | No | https://www.minew.com/uploads/MS88SF3_V1.0-nRF52833-Datasheet.pdf
 | 1 | U2 | BQ24072RGTR | Battery management | Texas Instruments | No | https://www.ti.com/lit/gpn/BQ24072 (http://www.ti.com/lit/ds/symlink/bq24075.pdf)
 | 1 | U3 | IP4234CZ6 | ESD protection for USB 2.0 | Nexperia | No | https://assets.nexperia.com/documents/data-sheet/IP4234CZ6.pdf
 | 1 | U4 | MS88SF31 | BLE module | Minew | No | https://www.minew.com/uploads/MS88SF3_V1.0-nRF52833-Datasheet.pdf
 | 1 | U5 | BQ24072RGTR | Battery management | Texas Instruments | No | https://www.ti.com/lit/gpn/BQ24072 (http://www.ti.com/lit/ds/symlink/bq24075.pdf)
 | 1 | U6 | IP4234CZ6 | ESD protection for USB 2.0 | Nexperia | No | https://assets.nexperia.com/documents/data-sheet/IP4234CZ6.pdf
Collated Components:
Item | Qty | Reference(s) | MFG | Description/Value | Manufacturer | Replaceable | Datasheet | Comments
1 | 2 | C1, C4 | 04023D105KAT2A | 1 µF ±10% 25V Ceramic Capacitor X5R 0402 (1005 Metric) | KYOCERA AVX | Yes | https://datasheets.kyocera-avx.com/C0GNP0-Dielectric.pdf
2 | 4 | C2, C3, C5, C6 | 0402YD475MAT2A | 4.7 µF ±20% 16V Ceramic Capacitor X5R 0402 (1005 Metric) | KYOCERA AVX | Yes | https://datasheets.kyocera-avx.com/cx5r.pdf
3 | 2 | D1, D3 | LTST-C193KRKT-5A | LED Red 0603 (1608 Metric) 2VF 5mA IF | Lite-On Inc. | Yes | https://optoelectronics.liteon.com/upload/download/DS22-2005-077/LTST-C193KRKT-5A.PDF
4 | 2 | D2, D4 | LTST-C194TBKT | LED Blue 0603 (1608 Metric) 3.3VF 20mA IF | Lite-On Inc. | Yes | https://optoelectronics.liteon.com/upload/download/DS22-2010-0025/LTST-C194TBKT.PDF
5 | 2 | J1, J4 | 2169900003 | Connector:USB_C_Receptacle_USB2.0 | Molex | No | https://www.molex.com/webdocs/datasheets/pdf/en-us/2169900003_IO_CONNECTORS.pdf (https://www.usb.org/sites/default/files/documents/usb_type-c.zip)
6 | 2 | J2, J5 | BM02B-ACHSS-GAN-TF(LF)(SN) | Connector:Conn_01x02_Female | ACH Connector | No | https://media.digikey.com/pdf/Data%20Sheets/JST%20PDFs/ACH_1.2Pitch_DisconnectableCrimp.pdf
8 | 4 | R1, R2, R7, R8 | ERJ-U02F5101X | 5.1 kOhms ±1% 0.1W, 1/10W Chip Resistor 0402 (1005 Metric) Anti-Sulfur, Automotive AEC-Q200 Thick Film | Panasonic Electronic Components | Yes | https://industrial.panasonic.com/cdbs/www-data/pdf/RDP0000/AOA0000C334.pdf
9 | 4 | R3, R4, R9, R10 | RC0402FR-7W10KL | 10 kOhms ±1% 0.125W, 1/8W Chip Resistor 0402 (1005 Metric) Moisture Resistant Thick Film | Yageo | Yes | https://www.yageo.com/upload/media/product/productsearch/datasheet/rchip/PYu-RC_Group_51_RoHS_L_11.pdf
10 | 2 | R5, R11 | ERJ-2RKF4700X | 470 Ohms ±1% 0.1W, 1/10W Chip Resistor 0402 (1005 Metric) Automotive AEC-Q200 Thick Film | Panasonic Electronic Components | Yes | https://industrial.panasonic.com/cdbs/www-data/pdf/RDA0000/AOA0000C304.pdf
11 | 2 | R6, R12 | ERJ-2RKF62R0X | 62 Ohms ±1% 0.1W, 1/10W Chip Resistor 0402 (1005 Metric) Automotive AEC-Q200 Thick Film | Panasonic Electronic Components | Yes | https://industrial.panasonic.com/cdbs/www-data/pdf/RDA0000/AOA0000C304.pdf
12 | 2 | S1, S3 | TL3330AF260QG | Push button | E Switch | No | https://sten-eswitch-13110800-production.s3.amazonaws.com/system/asset/product_line/data_sheet/163/TL3330.pdf
13 | 2 | S2, S4 | EG1215AA | On/off switch | E Switch | No | https://media.digikey.com/pdf/Data%20Sheets/E-Switch%20PDFs/EG1215_Series_Ds.pdf
15 | 2 | U1, U4 | MS88SF31 | BLE module | Minew | No | https://www.minew.com/uploads/MS88SF3_V1.0-nRF52833-Datasheet.pdf | MS88SF31 with the nrf52833 is correct. This is a personal project that I intend to make into a product.
16 | 2 | U2, U5 | BQ24072RGTR | Battery management | Texas Instruments | No | https://www.ti.com/lit/gpn/BQ24072 (http://www.ti.com/lit/ds/symlink/bq24075.pdf)
17 | 2 | U3, U6 | IP4234CZ6 | Brand : NXP Footprint ：SOT457, ESD protection for USB 2.0 | Nexperia | No | https://assets.nexperia.com/documents/data-sheet/IP4234CZ6.pdf | Yes, Brand : NXP Footprint ：SOT457 is correct

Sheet: Top-pos
Ref | Val | PosX | PosY | Rot | Side
C1 | CAP | -15.70375 | 14.7375 | 180 | top
C2 | CAP | -17.817313 | 11.525234 | 90 | top
C3 | CAP | -20.35 | 18.4375 | 180 | top
C4 | CAP | 20.748402 | 21.89625 | -90 | top
C5 | CAP | 23.960668 | 19.782687 | 180 | top
C6 | CAP | 17.048402 | 17.25 | -90 | top
D1 | LED | -59.15 | -10.7 | 180 | top
D2 | LED | -63.05 | -10.1 | 180 | top
D3 | LED | 59.15 | -9.33 | 0 | top
D4 | LED | 63.05 | -9.93 | 0 | top
J1 |  | -20.88 | -27.299999 | 0 | top
J2 | JST_BM02B | -3.65 | 10.5 | -90 | top
J3 |  | -48.317313 | -31.744766 | -90 | top
J5 | JST_BM02B | 3.65 | 10.5 | 90 | top
J6 |  | 63.05 | -17.225 | 90 | top
R1 | RES | -26.65 | -22.2 | 0 | top
R2 | RES | -24.15 | -22.6 | 90 | top
R3 | RES | -16.25 | 16.8375 | 90 | top
R4 | RES | -15.25 | 16.8375 | 90 | top
R5 | RES | -58.86 | -9.5 | 180 | top
R6 | RES | -62.76 | -8.9 | 180 | top
R7 | RES | 24.15 | -22.6 | 90 | top
R8 | RES | 26.65 | -22.2 | 180 | top
R9 | RES | 18.648402 | 21.35 | 180 | top
R10 | RES | 18.648402 | 22.35 | 180 | top
R11 | RES | 58.86 | -10.53 | 0 | top
R12 | RES | 62.76 | -11.13 | 0 | top
S1 | TL3330AF260QG | -10.225 | -11.305 | 90 | top
S2 | SW_EG1215AA | -8.85 | 28.5 | 90 | top
S3 | TL3330AF260QG | 10.2 | 32.305 | -90 | top
S4 | SW_EG1215AA | 8.852 | -7.5 | -90 | top
U1 | MS88SF31 | -62.6 | -31.3 | 160 | top
U2 | BQ24075 | -18.9 | 15.5 | -90 | top
U3 | SOT-457 | -30.917313 | -22.594766 | 0 | top
U4 | MS88SF31 | 62.6 | -31.3 | -160 | top
U5 | BQ24075 | 19.985902 | 18.7 | 0 | top
U6 | SOT-457 | 31.3 | -22.2 | -90 | top
USB-C | USB-C | -25.5 | -31.9 | 0 | top
USB-C | USB-C | 25.5 | -31.9 | 0 | top

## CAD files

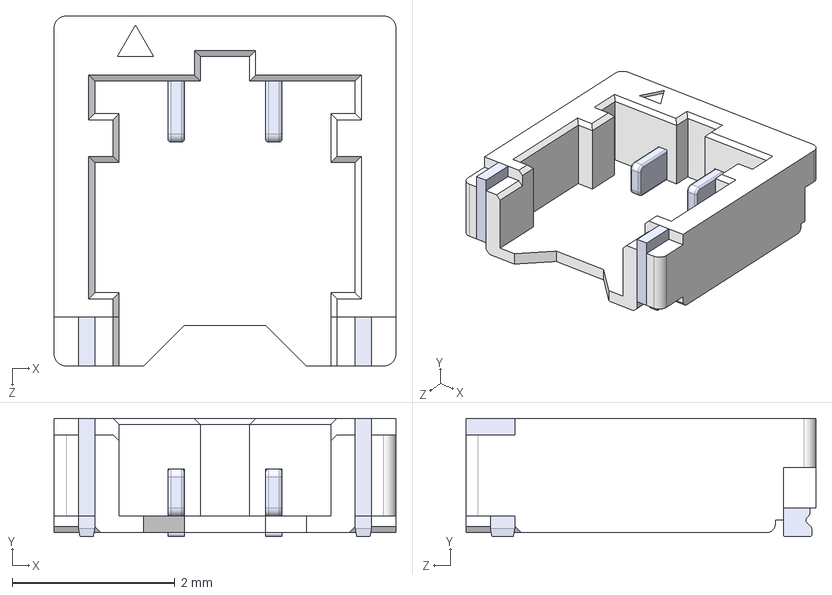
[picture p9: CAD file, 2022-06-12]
Modules/BM02B-ACHSS-GAN-TF_LF__SN_/BM02B-ACHSS-GAN-TF_LF__SN_.step
4.20 x 1.45 x 4.30 mm

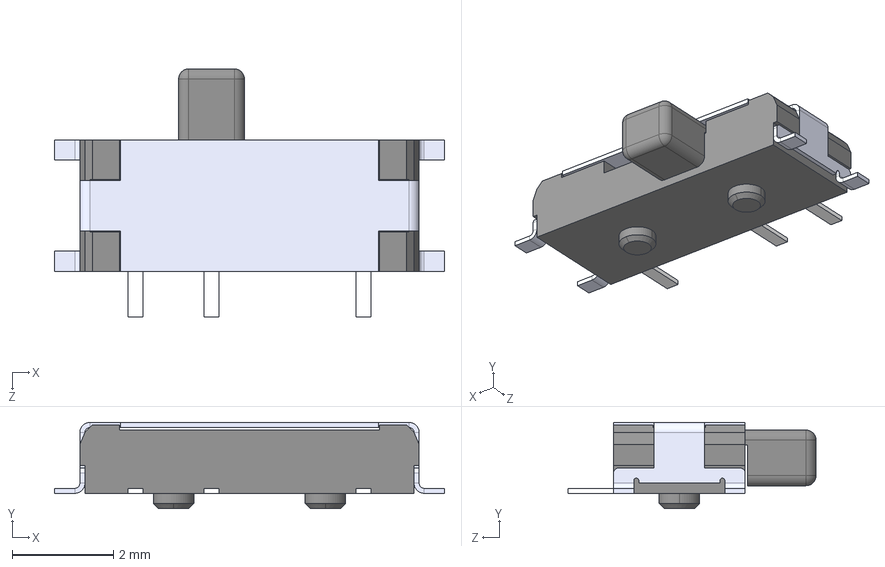
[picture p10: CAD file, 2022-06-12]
Modules/EG1215AA/EG1215AA.step
7.70 x 1.70 x 4.90 mm

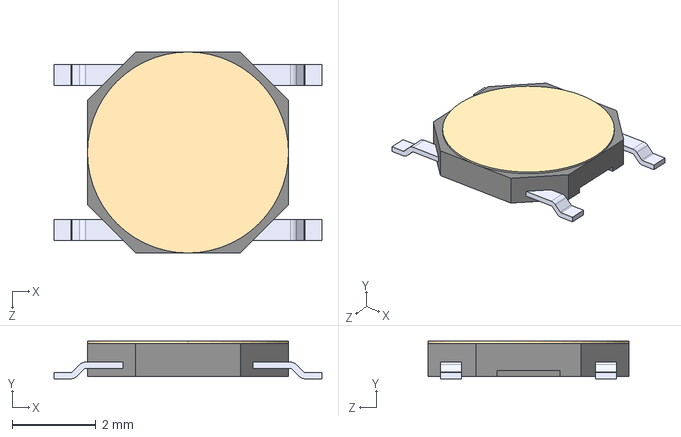
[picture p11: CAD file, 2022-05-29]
Modules/PTS526_SM08_SMTR2_LFS/PTS526_SM08_SMTR2_LFS.step
6.40 x 0.9 x 4.80 mm

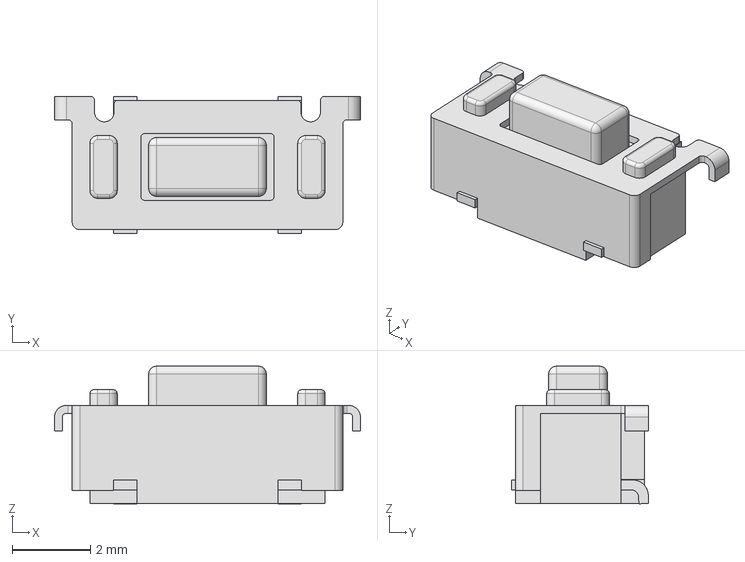
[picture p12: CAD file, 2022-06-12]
Modules/TL3330AF260QG/TL3330AF260QG--3DModel-STEP-520916.STEP
7.80 x 3.50 x 3.51 mm

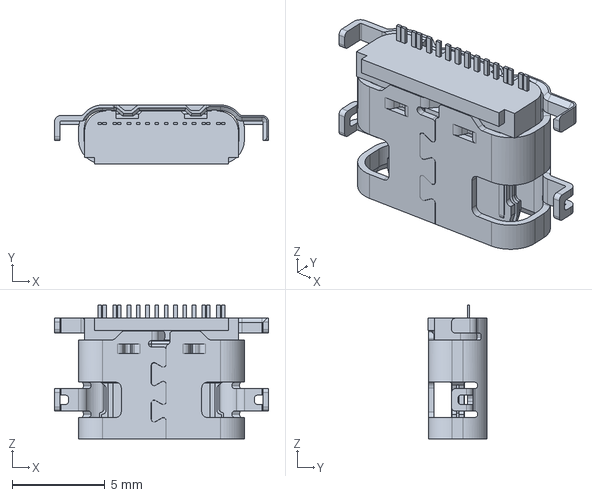
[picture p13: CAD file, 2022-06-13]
Modules/2169900003/2169900001.stp
11.5 x 3.18 x 7.20 mm

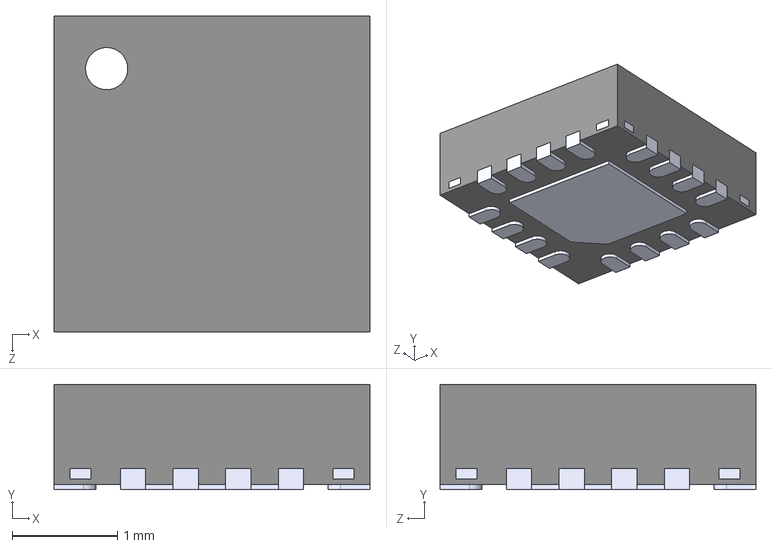
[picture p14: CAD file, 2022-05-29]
Modules/BQ24075TRGTT/BQ24075TRGTT.step
3.00 x 1.00 x 3.00 mm

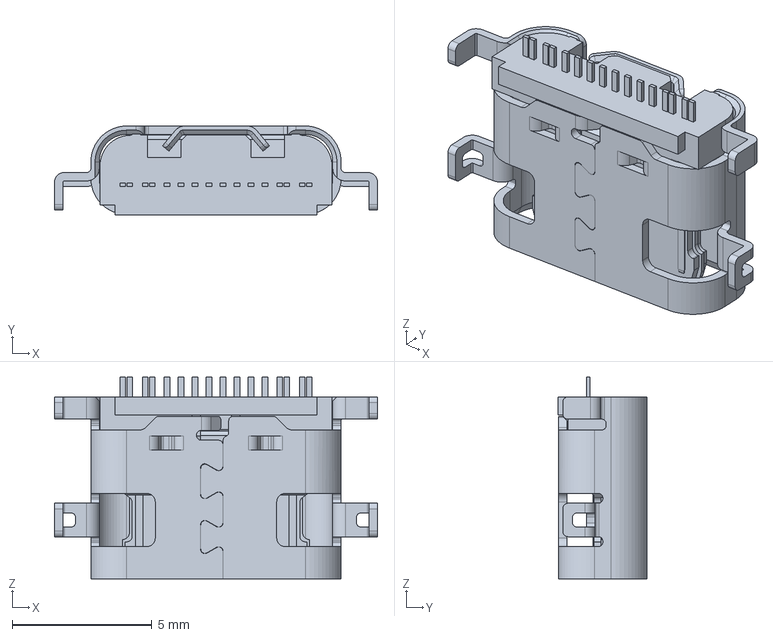
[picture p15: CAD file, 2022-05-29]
Modules/2169900003/2169900003.stp
11.5 x 3.18 x 7.20 mm

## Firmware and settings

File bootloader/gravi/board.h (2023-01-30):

/*
 * The MIT License (MIT)
 *
 * Copyright (c) 2020 Nick Winans
 *
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
 * THE SOFTWARE IS PROVIDED "AS IS", WITHOUT WARRANTY OF ANY KIND, EXPRESS OR
 * IMPLIED, INCLUDING BUT NOT LIMITED TO THE WARRANTIES OF MERCHANTABILITY,
 * FITNESS FOR A PARTICULAR PURPOSE AND NONINFRINGEMENT. IN NO EVENT SHALL THE
 * AUTHORS OR COPYRIGHT HOLDERS BE LIABLE FOR ANY CLAIM, DAMAGES OR OTHER
 * LIABILITY, WHETHER IN AN ACTION OF CONTRACT, TORT OR OTHERWISE, ARISING FROM,
 * OUT OF OR IN CONNECTION WITH THE SOFTWARE OR THE USE OR OTHER DEALINGS IN
 * THE SOFTWARE.
 */

#ifndef _GRAVI_H
#define _GRAVI_H

#define _PINNUM(port, pin)    ((port)*32 + (pin))

#define UICR_REGOUT0_VALUE UICR_REGOUT0_VOUT_3V3

/*------------------------------------------------------------------*/
/* LED
 *------------------------------------------------------------------*/
#define LEDS_NUMBER       1
#define LED_PRIMARY_PIN   _PINNUM(0, 17) // Blue
#define LED_STATE_ON      1

/*------------------------------------------------------------------*/
/* BUTTON
 *------------------------------------------------------------------*/
#define BUTTONS_NUMBER    2  // Only reset connected
#define BUTTON_1          _PINNUM(0, 18)  // unusable: RESET
#define BUTTON_2          _PINNUM(0, 14)  // no connection
#define BUTTON_PULL       NRF_GPIO_PIN_PULLUP

//--------------------------------------------------------------------+
// BLE OTA
//--------------------------------------------------------------------+
#define BLEDIS_MANUFACTURER  "gravikb"
#define BLEDIS_MODEL         "gravi"

//--------------------------------------------------------------------+
// USB
//--------------------------------------------------------------------+
#define USB_DESC_VID           0x239A
#define USB_DESC_UF2_PID       0x00B3
#define USB_DESC_CDC_ONLY_PID  0x00B3

#define UF2_PRODUCT_NAME  "gravi"
#define UF2_VOLUME_LABEL  "GRAVI"
#define UF2_BOARD_ID      "nRF52840-gravi"
#define UF2_INDEX_URL     "https://gravikb.com/docs/gravi"

#endif // _GRAVI_H

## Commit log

2022-05-26 Added keyboard pcb
    [main.kicad_pcb, main.kicad_sch]
2022-05-29 Add mount holes
    [main.kicad_pcb, main.kicad_sch]
2022-05-29 Copper fill
    [2169900003.stp, BQ24075TRGTT.step, PTS526_SM08_SMTR2_LFS.step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]
2022-05-31 Version 2
    [main.kicad_pcb, main.kicad_sch]
2022-06-12 Remade entire board
    [BM02B-ACHSS-GAN-TF_LF__SN_.step, EG1215AA.step, TL3330AF260QG--3DModel-STEP-520916.STEP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]
2022-06-13 Finalized design
    [2169900001.stp, main.kicad_pcb, main.kicad_sch]
2022-06-16 Pards sourced
    [main.kicad_pcb]
2022-06-18 V0.2 close to done
    [main.kicad_pcb, main.kicad_sch]
2022-06-18 Shrank outline
    [main.kicad_pcb]
2022-08-04 Just need to change ESD
    [main.csv, main.kicad_pcb, main.kicad_sch]
2022-08-05 Difficult circuitry complete, just wire
    [main.kicad_pcb, main.kicad_sch]
2022-08-05 Left half complete
    [main.kicad_pcb]
2022-08-08 Fix curve issues
    [main.kicad_pcb]
2023-01-17 Update to V3
    [main-B_Cu.gbl, main-B_Mask.gbs, main-B_Paste.gbp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]
